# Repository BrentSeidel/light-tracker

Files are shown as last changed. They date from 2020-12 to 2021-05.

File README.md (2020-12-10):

# light-tracker
This is primarily a development project to get a working pan-tilt
head driven by stepper motors that can be used for a variety of
applications (the one in the back of my mind is pointing a radio
telescope).  This project uses a square 2x2 array of
photo-transistors separated by a X shaped shade and a
microcontroller to drive the steppers to equalize the light to the
phototransistors.

## Dependencies
### 3D Models
* The 3D models use items from my "things" repository at https://github.com/BrentSeidel/Things.git
* The gears come from sadr0b0t's "pd-gears" repository at https://github.com/sadr0b0t/pd-gears.git
### Software
* The software is written in a tiny-lisp from https://github.com/BrentSeidel/Ada-Lisp.git
* The hardware interfaces are from https://github.com/BrentSeidel/BBS-BBB-Ada.git
* I'm using an Arduino-Due as the microcontroller using https://github.com/BrentSeidel/Ada-Arduino-Due.git
* The low-level runtime should eventually wind up in AdaCore's "bb-runtimes" repostory at https://github.com/AdaCore/bb-runtimes.git
* I have a runtime version in my for at https://github.com/BrentSeidel/bb-runtimes.git, but
due to changes upstream, it no longer builds and I haven't had the time
to figure out why.
* It should be possible to adapt this to another microcontroller, either
bare metal or Linux based (such as a Raspberry PI).

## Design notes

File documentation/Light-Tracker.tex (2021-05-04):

\documentclass[10pt, openany]{book}

\usepackage{fancyhdr}
\usepackage{imakeidx}

\usepackage{amsmath}
\usepackage{amsfonts}

\usepackage{geometry}
\geometry{letterpaper}

\usepackage{fancyvrb}
\usepackage{fancybox}

\usepackage{gensymb}
\usepackage{pstricks}
\usepackage{graphicx}
\DeclareGraphicsExtensions{.eps}
\DeclareGraphicsRule{.eps}{eps}{.eps}{}

\usepackage{url}
%
% Rules to allow import of graphics files in EPS format
%
\usepackage{graphicx}
\DeclareGraphicsExtensions{.eps}
\DeclareGraphicsRule{.eps}{eps}{.eps}{}
%
%  Include the listings package
%
\usepackage{listings}
%
%  Define Tiny Lisp based on Common Lisp
%
\lstdefinelanguage[Tiny]{Lisp}[]{Lisp}{morekeywords=[13]{atomp, bit-vector-p, car, cdr, char-downcase, char-code, char-upcase, compiled-function-p, dowhile, dump, exit, fresh-line, if, code-char, lambda, msg, nullp, parse-integer, peek8, peek16, peek32, poke8, poke16, poke32, quote, read-line, reset, setq, simple-bit-vector-p, simple-string-p, simple-vector-p, string-downcase, string-upcase}}
%
% Macro definitions
%
\newcommand{\operation}[1]{\textbf{\texttt{#1}}}
\newcommand{\package}[1]{\texttt{#1}}
\newcommand{\function}[1]{\texttt{#1}}
\newcommand{\constant}[1]{\emph{\texttt{#1}}}
\newcommand{\keyword}[1]{\texttt{#1}}
\newcommand{\datatype}[1]{\texttt{#1}}
\newcommand{\tl}{Tiny-Lisp}
\newcommand{\cl}{Common Lisp}
%
% Front Matter
%
\title{Light Tracker}
\author{Brent Seidel \\ Phoenix, AZ}
\date{ \today }
%========================================================
%%% BEGIN DOCUMENT
\begin{document}
%
% Produce the front matter
%
\frontmatter
\maketitle
\begin{center}
This document is \copyright 2021 Brent Seidel.  All rights reserved.

\paragraph{}Note that this is a draft version and not the final version for publication.
\end{center}
\tableofcontents

\mainmatter
%----------------------------------------------------------
\chapter{Introduction}
The light tracker was conceived as a way to test a 3-D printed pan and tilt platform.

%----------------------------------------------------------
\chapter{Hardware}
\section{Electronics}
\subsection{Micro-controller Requirements}
There are four photo-transistors light sensors, thus 4 analog inputs are required.  Each stepper motor requires 4 digital output lines.  For the two steppers, a total of 8 outputs are required.  Should limit switches be added, a few digital inputs will also be required.  The micro-controller that I'm using is an Arduino Due, which has ample resources for this project.

\subsection{Light Sensors}
Each light sensor consists of a photo-transistor in series with a 1k$\Omega$ resistor.  The center tap is connected to one of the analog inputs.  The sensors are arranged in a $2 \times 2$ grid with a ``+'' shaped shade between them.  The sensors are tied to the analog inputs as shown in figure \ref{fig:Sensors}.

\begin{figure}[htb]
  \begin{center}
    
    \caption{Light Sensor Arrangement}
    \label{fig:Sensors}
  \end{center}
\end{figure}

\subsection{Stepper Motor Control}
The stepper motors are controller by two TB6612 dual H-bridge controllers (Adafruit p/n 2448).  Each of these controls one of the stepper motors.  The first one, H1 is used to control the panning motor and the other one, H2 is used to control the tilt motor.

\subsection{Connections}
Both the controller and the pan tilt have two DB9 connectors (see figure \ref{fig:D9}).  One is used for the sensors (see table \ref{tbl:Sensor}) and the other is used for the stepper motors (see table \ref{tbl:Stepper}).

The cables are made using CAT5 cables and are wired up so that pins 1 \& 6, 2 \& 7, 4 \& 9, and 5 \& 9 are each on a separate twisted pair.  Which pair used is not particularly important, just that the pair is wired the same at both ends.

\begin{figure}[htb]
  \begin{center}
    
    \caption{DB-9 Connector Pin Numbers}
    \label{fig:D9}
  \end{center}
\end{figure}

\begin{table}
  \begin{center}
    \caption{Light Sensor Pinout}
    \label{tbl:Sensor}
    \begin{tabular}[htb]{|c|l|}
      \hline
      Pin & Usage \\
      \hline
      1 & Analog 4 \\
      2 & Analog 3 \\
      3 & n.c. \\
      4 & Analog 2 \\
      5 & Analog 1 \\
      6 & +V (for analog 4)\\
      7 & +V (for analog 3)\\
      8 & +V (for analog 2)\\
      9 & +V (for analog 1)\\
      \hline
    \end{tabular}
  \end{center}
\end{table}

\begin{table}
  \begin{center}
    \caption{Stepper Motor Connector Pinout}
    \label{tbl:Stepper}
    \begin{tabular}[htb]{|c|l|}
      \hline
      Pin & Usage \\
      \hline
      1 & H1, MA+ (gpio 22 green) \\
      2 & H1, MB+ (gpio 24 red) \\
      3 & n.c. \\
      4 & H2, MA+ (gpio 28 green) \\
      5 & H2, MB+ (gpio 30 red) \\
      6 & H1, MA- (gpio 23 grey) \\
      7 & H1, MB- (gpio 25 yellow) \\
      8 & H2, MA- (gpio 29 grey) \\
      9 & H2, MB- (gpio 31 yellow) \\
      \hline
    \end{tabular}
  \end{center}
\end{table}

\section{Mechanical}
\subsection{Gearing}
Both stepper motors have a 20 tooth gear and are 400 steps per revolution.

The tilt gear has 50 teeth giving a $\frac{2}{5}$ gear ratio.  With the gearing, 1000 steps of the motor will completely rotate the tilt frame.  This is 0.36\degree per step or 2.78 steps per degree.

The pan gear has 100 teeth giving a $\frac{1}{5}$ gear ratio.  With the gearing, 2000 steps of the motor will completely rotate the pan head, giving 0.18\degree per steps or 5.56 steps per degree.

\subsection{Control Box}

\subsection{Pan/Tilt Head}

%----------------------------------------------------------
\chapter{Software}

\end{document}

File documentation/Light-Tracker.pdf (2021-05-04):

# Light Tracker

Brent Seidel
Phoenix, AZ

March 10, 2021

ii

This document is

c 2021 Brent Seidel. All rights reserved.

Note that this is a draft version and not the final version for publication.

# Contents

1 Introduction | 1
2 Hardware | 2
3 Software | 5

iii

iv | CONTENTS

# Chapter 1

# Introduction

The light tracker was conceived as a way to test a 3-D printed pan and tilt platform.

1

# Chapter 2

# Hardware

## 2.1 Electronics

### 2.1.1 Micro-controller Requirements

There are four photo-transistors light sensors, thus 4 analog inputs are required. Each stepper motor requires 4 digital output lines. For the two steppers, a total of 8 outputs are required. Should limit switches be added, a few digital inputs will also be required. The micro-controller that I’m using is an Arduino Due, which has ample resources for this project.

### 2.1.2 Light Sensors

Each light sensor consists of a photo-transistor in series with a 1kΩ resistor. The center tap is connected to one of the analog inputs. The sensors are arranged in a 2 × 2 grid with a “+” shaped

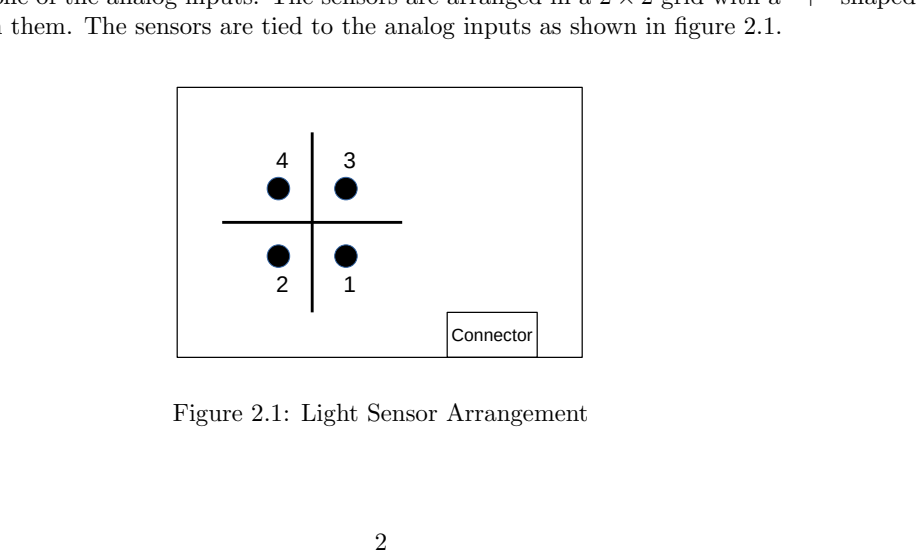
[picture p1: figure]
Connector; Figure 2.1: Light Sensor Arrangement

shade between them. The sensors are tied to the analog inputs as shown in figure 2.1.

2.2. MECHANICAL | 3

Table 2.1: Light Sensor Pinout
Pin | Usage
1 2 3 4 5 6 7 8 9 | Analog 4 Analog 3 n.c. Analog 2 Analog 1 +V (for analog 4) +V (for analog 3) +V (for analog 2) +V (for analog 1)

### 2.1.3 Stepper Motor Control

The stepper motors are controller by two TB6612 dual H-bridge controllers (Adafruit p/n 2448). Each of these controls one of the stepper motors. The first one, H1 is used to control the panning motor and the other one, H2 is used to control the tilt motor.

### 2.1.4 Connections

Both the controller and the pan tilt have two DB9 connectors (see figure 2.2). One is used for the

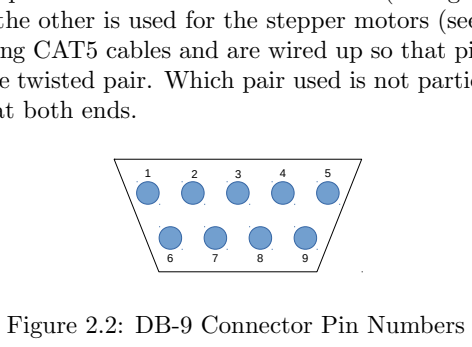
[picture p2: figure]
Figure 2.2: DB-9 Connector Pin Numbers

sensors (see table 2.1) and the other is used for the stepper motors (see table 2.2).
The cables are made using CAT5 cables and are wired up so that pins 1 & 6, 2 & 7, 4 & 9, and 5 & 9 are each on a separate twisted pair. Which pair used is not particularly important, just that the pair is wired the same at both ends.

## 2.2 Mechanical

### 2.2.1 Gearing

Both stepper motors have a 20 tooth gear and are 400 steps per revolution. The tilt gear has 50 teeth giving a 2
5

gear ratio. With the gearing, 1000 steps of the motor will completely rotate the tilt frame. This is 0.36◦per step or 2.78 steps per degree. The pan gear has 100 teeth giving a 1
5

gear ratio. With the gearing, 2000 steps of the motor will completely rotate the pan head, giving 0.18◦per steps or 5.56 steps per degree.

4 | CHAPTER 2. HARDWARE

Table 2.2: Stepper Motor Connector Pinout
Pin | Usage
1 2 3 4 5 6 7 8 9 | H1, MA+ (gpio 22 green) H1, MB+ (gpio 24 red) n.c. H2, MA+ (gpio 28 green) H2, MB+ (gpio 30 red) H1, MA- (gpio 23 grey) H1, MB- (gpio 25 yellow) H2, MA- (gpio 29 grey) H2, MB- (gpio 31 yellow)

### 2.2.2 Control Box

### 2.2.3 Pan/Tilt Head

# Chapter 3

# Software

5

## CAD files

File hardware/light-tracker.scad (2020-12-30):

use <../../Things/bbs_constants.scad>
use <../../Things/bbs_connectors.scad>

module LOCAL_led(height)
{
  lead_space = 2.54;
  translate([0, lead_space/2, -0.5]) cube([1, 1, height]);
  translate([0, -lead_space/2, -0.5]) cube([1, 1, height]);
  translate([-20, lead_space/2, -0.5]) cube([41, 1, height/2]);
  translate([-20, -lead_space/2, -0.5]) cube([41, 1, height/2]);
}
module phototransitor_mount()
{
  difference()
  {
    union()
    {
      cube([40, 80, 4]);
      translate([0, 39, 0]) cube([40, 2, 40]);
      translate([19, 20, 0]) cube([2, 40, 40]);
      translate([-20, 0, 0]) cube([20, 30, 4]);
    }
    union()
    {
      translate([10, 10, -0.5]) cylinder(r=screw_8_size()/2, h=5);
      translate([30, 10, -0.5]) cylinder(r=screw_8_size()/2, h=5);
      translate([10, 70, -0.5]) cylinder(r=screw_8_size()/2, h=5);
      translate([30, 70, -0.5]) cylinder(r=screw_8_size()/2, h=5);
      translate([14, 34, 0]) LOCAL_led(5);
      translate([14, 46, 0]) LOCAL_led(5);
      translate([26, 34, 0]) LOCAL_led(5);
      translate([26, 46, 0]) LOCAL_led(5);
      translate([-10, 15, -0.5]) rotate([0, 0, 90]) bbs_d_cutout(1, 5);
    }
  }
}

rotate([0, 0, 0]) phototransitor_mount();

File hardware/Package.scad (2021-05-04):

use <../../Things/bbs_arduino.scad>
use <../../Things/bbs_boards.scad>
use <../../Things/bbs_breadboard.scad>
use <../../Things/bbs_connectors.scad>
use <../../Things/bbs_constants.scad>
use <../../Things/bbs_panel.scad>
use <../../Things/bbs_rack.scad>
use <../../Things/bbs_switches.scad>
use <../../Things/bbs_tray.scad>
//
//  This file contains items for mounting and housing the electronics to control the light-tracker.
//
module tray()
{
  screw_size = 3*screw_6_size()/4;
  screw_hole = screw_6_size()/2;
  difference()
  {
    union()
    {
      bbs_tray(5, 7, false);
      translate([150, 70, 0]) rotate([0, 0, 90]) bbs_tb6612_standoffs(5, screw_size, 12);
      translate([115, 70, 0]) rotate([0, 0, 90]) bbs_tb6612_standoffs(5, screw_size, 12);
      translate([0, 10, 0]) bbs_arduino_mega2560_standoffs(5, screw_size, 12);
      translate([110, 10, 0]) bbs_quarter_permaprotoboard_standoffs(5, screw_size, 12);
    }
    union()
    {
      translate([150, 70, -1]) rotate([0, 0, 90]) bbs_tb6612_standoffs(7, screw_hole, 12);
      translate([115, 70, -1]) rotate([0, 0, 90]) bbs_tb6612_standoffs(7, screw_hole, 12);
      translate([0, 10, -1]) bbs_arduino_mega2560_standoffs(7, screw_hole, 12);
      translate([110, 10, -1]) bbs_quarter_permaprotoboard_standoffs(7, screw_hole, 12);
      translate([25, 15, -1]) minkowski()
      {
        cube([30, 80, 7]);
        cylinder(r=5, h=7);
      }
      translate([125, 15, -1]) minkowski()
      {
        cube([10, 80, 7]);
        cylinder(r=5, h=7);
      }
      translate([75, 15, -1]) minkowski()
      {
        cube([5, 80, 7]);
        cylinder(r=5, h=7);
      }
    }
  }
}

module rack()
{
  bbs_rack(5, 7, 3);
}

module connector_panel()
{
  difference()
  {
    bbs_panel(5, 3);
    union()
    {
      translate([30, 40, -0.5]) rotate([0, 0, 90]) bbs_d_cutout(1, 3);
      translate([30, 80, -0.5]) rotate([0, 0, 90]) bbs_d_cutout(1, 3);
      translate([18, 40, 1.5]) linear_extrude(height = 0.6) rotate([0, 0, -90])
              text("Stepper", halign="center", valign="center", size=6, font="Liberation Sans:Bold");
      translate([18, 80, 1.5]) linear_extrude(height = 0.6) rotate([0, 0, -90])
              text("Sensors", halign="center", valign="center", size=6, font="Liberation Sans:Bold");
    }
  }
}

module switch_panel()
{
  difference()
  {
    bbs_panel(5, 2);
    union()
    {
      translate([20, 90, -0.1]) bbs_spdt_switch_cutout(2.2);
      translate([20, 70, -0.1]) bbs_spdt_switch_cutout(2.2);
      translate([20, 50, -0.1]) bbs_spdt_switch_cutout(2.2);
      translate([20, 30, -0.1]) bbs_spdt_switch_cutout(2.2);
      translate([7, 90, 1.5]) linear_extrude(height = 0.6) rotate([0, 0, -90])
              text("Stop", halign="center", valign="center", size=6, font="Liberation Sans:Bold");
      translate([30, 90, 1.5]) linear_extrude(height = 0.6) rotate([0, 0, -90])
              text("Run", halign="center", valign="center", size=6, font="Liberation Sans:Bold");
    }
  }
}

//tray();
//translate([150, 70, 10]) rotate([0, 0, 90]) color("red") bbs_tb6612();
//translate([115, 70, 10]) rotate([0, 0, 90]) color("red") bbs_tb6612();
//translate([0, 10, 10]) color("green") bbs_arduino_mega2560();
//translate([110, 10, 10]) color("red") bbs_quarter_permaprotoboard();
//rack();
//connector_panel();
switch_panel();

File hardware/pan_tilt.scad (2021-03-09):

//
//  Models for pan and tilt mounting
//
use <../../Things/bbs_constants.scad>
use <../../Things/bbs_shapes.scad>
use <../../Things/bbs_stepper.scad>
use <../../pd-gears/pd-gears.scad>

module LOCAL_base_arm()
{
  d1 = pitch_radius(5, 100);
  d2 = pitch_radius(5, 20);
  width=20;
  length=d1+d2+0;
  difference()
  {
    union()
    {
      translate([-width/2, 0, 0]) cube([width, length, 4]);
      translate([0, length, 0]) cylinder(r=10, h=4);
      translate([-width/2, d1+5, 0]) cube([width, 4, 20]);
    }
    union()
    {
      translate([0, length, -0.5]) cylinder(r=screw_8_size()/2, h=5);
      translate([0, length-20, -0.5]) cylinder(r=screw_8_size()/2, h=5);
      translate([0, length, 2]) cylinder(r=screw_8_size()/2+2.5, h=5);
      translate([0, length-20, 2]) cylinder(r=screw_8_size()/2+2.5, h=5);
      translate([0, d1+4.5, 15]) rotate([-90, 0, 0]) cylinder(r=2, h=5);
      translate([6, d1+4.5, 15]) rotate([-90, 0, 0]) cylinder(r=2, h=5);
      translate([-6, d1+4.5, 15]) rotate([-90, 0, 0]) cylinder(r=2, h=5);
    }
  }
}
module LOCAL_base_motor()
{
  d1 = pitch_radius(5, 100);
  d2 = pitch_radius(5, 20);
  difference()
  {
    rotate([0, 0, 0]) translate([-20, -15, 0]) cube([40, 135, 4]);
    union()
    {
      translate([0, (d1+d2), -0.5]) bbs_NEMA17_holes(5, true);
      translate([-0.5, 116, -0.5]) cube([1, 5, 1.5]);
    }
  }
}
//
//  This is the base that everything rests on.  it contains a hole for the vertical
//  shaft and a mount for a stepper motor.
//
module base(pan_shaft)
{
  difference()
  {
    union()
    {
      LOCAL_base_arm();
      rotate([0, 0, 90]) LOCAL_base_arm();
      rotate([0, 0, 180]) LOCAL_base_arm();
      rotate([0, 0, 270]) LOCAL_base_arm();
      rotate([0, 0, 45]) LOCAL_base_motor();
    }
    translate([0, 0, -0.5]) cylinder(r=pan_shaft, h=5);
  }
}
//
//  Feet to support the base.  These are bolted to the base and have holes where legs could
//  be attached to them.  They can also be used without legs to support the base on a table
//  top, or similar.
//
module foot()
{
  union()
  {
    difference()
    {
      cube([20, 40, 4]);
      union()
      {
        translate([10, 10, -0.5]) cylinder(r=screw_8_size()/2, h=5, $fn=12);
        translate([10, 30, -0.5]) cylinder(r=screw_8_size()/2, h=5, $fn=12);
      }
    }
    rotate([10, 0, 0]) difference()
    {
      cube([20, 4, 40]);
      union()
      {
        translate([10, -0.5, 10]) rotate([-90, 0, 0]) cylinder(r=screw_8_size()/2, h=5, $fn=12);
        translate([10, -0.5, 30]) rotate([-90, 0, 0]) cylinder(r=screw_8_size()/2, h=5, $fn=12);
      }
    }
    difference()
    {
      cube([4, 30, 20]);
      translate([-0.5, 0, 20]) rotate([-30, 0, 0]) cube([5, 40, 20]);
    }
  }
}
//
//  This part sits on the base.  It has an integrated gear that interfaces with with a gear
//  on the stepper motor.
//
module LOCAL_pan_panel(tilt_shaft)
{
  d1 = pitch_radius(5, 50);
  d2 = pitch_radius(5, 20);
  difference()
  {
    union()
    {
      cube([50, 4, 25]);
      hull()
      {
        translate([25, 4, 25]) rotate([90, 0, 0]) cylinder(r=25, h=4);
        translate([25, 4, 100]) rotate([90, 0, 0]) cylinder(r=15, h=4);
      }
      translate([50, 4, 0]) rotate([0, -90, 0]) bbs_fillet(10, 50);
      translate([0, 0, 0]) rotate([0, -90, 180]) bbs_fillet(10, 50);
    }
    union()
    {
      translate([25, 4.5, 100]) rotate([90, 0, 0]) cylinder(r=tilt_shaft, h=5);
      translate([25, 4.5, 20]) rotate([90, 0, 0]) cylinder(r=7, h=5);
      translate([25, 4.5, 80]) rotate([90, 0, 0]) cylinder(r=10, h=5);
      translate([4, 4.5, 12]) rotate([90, 0, 0]) cylinder(r=2, h=5);
      translate([4, 4.5, 18]) rotate([90, 0, 0]) cylinder(r=2, h=5);
      translate([46, 4.5, 12]) rotate([90, 0, 0]) cylinder(r=2, h=5);
      translate([46, 4.5, 18]) rotate([90, 0, 0]) cylinder(r=2, h=5);
      translate([25, 4.5, 100-d1-d2]) rotate([90, 0, 0]) bbs_NEMA17_holes(5, true);
    }
  }
}

module pan(pan_shaft, tilt_shaft)
{
  difference()
  {
    gear(5, 100, 4, 1);
    union()
    {
      translate([0, 0, -0.5]) cylinder(r=pan_shaft, h=5);
      for(t=[0:60:360])
      {
        rotate([0, 0, t]) translate([30, 0, -0.5]) cylinder(r=10, h=5);
      }
      for(t=[-45:30:45])
      {
        rotate([0, 0, t]) translate([60, 0, -0.5]) cylinder(r=10, h=5);
        rotate([0, 0, t]) translate([-60, 0, -0.5]) cylinder(r=10, h=5);
      }
    }
  }
  translate([-25, -59, 4]) LOCAL_pan_panel(tilt_shaft);
  translate([-25, 55, 4]) LOCAL_pan_panel(tilt_shaft);
}
//
//  This part attaches to the pan part and is used to tilt up and down.
//
module tilt(tilt_shaft)
{
  difference()
  {
    union()
    {
      gear(5, 50, 4, 1);
      translate([20, -16, 4]) rotate([0, -90, 0]) bbs_fillet(10, 40);
      translate([-20, -20, 4]) rotate([0, -90, 180]) bbs_fillet(10, 40);
    }
    union()
    {
      translate([0, 0, -0.5]) cylinder(r=tilt_shaft, h=5);
      for(t=[0:60:180])
      {
        rotate([0, 0, t]) translate([23, 0, -0.5]) cylinder(r=8, h=5);
      }
    }
  }
  difference()
  {
    translate([-20, -20, 4]) cube([20, 4, 100]);
    union()
    {
      for(z=[25:20:100])
      {
        translate([-10, -20.5, z]) rotate([-90, 0, 0]) cylinder(r=screw_8_size()/2, h=5);
      }
    }
  }
}
//
//  Drive gears for the stepper motors
//
module drive_gear()
{
  difference()
  {
    gear(5, 20, 4, 1);
    translate([0, 0, -0.5]) bbs_NEMA17_dshaft(5);
  }
}

//rotate([0, -90, 0]) foot();
//base(screw_8_size()/2);
translate([0, 0, 5]) pan(screw_8_size()/2, screw_8_size()/2);
//translate([0, -54, 104]) rotate([-90, 0, 0]) color("green") tilt(screw_8_size()/2);
//translate([0, 54, 104]) rotate([-90, 0, 180]) color("red") tilt(screw_8_size()/2);
//translate([0, -50, 104-pitch_radius(5, 50)-pitch_radius(5, 20)]) rotate([90, 7, 0])tilt_gear();
//translate([0, -54, 110]) cube([10, 108, 10]);

//tilt(screw_8_size()/2);
//translate([60, 0, 0]) drive_gear();

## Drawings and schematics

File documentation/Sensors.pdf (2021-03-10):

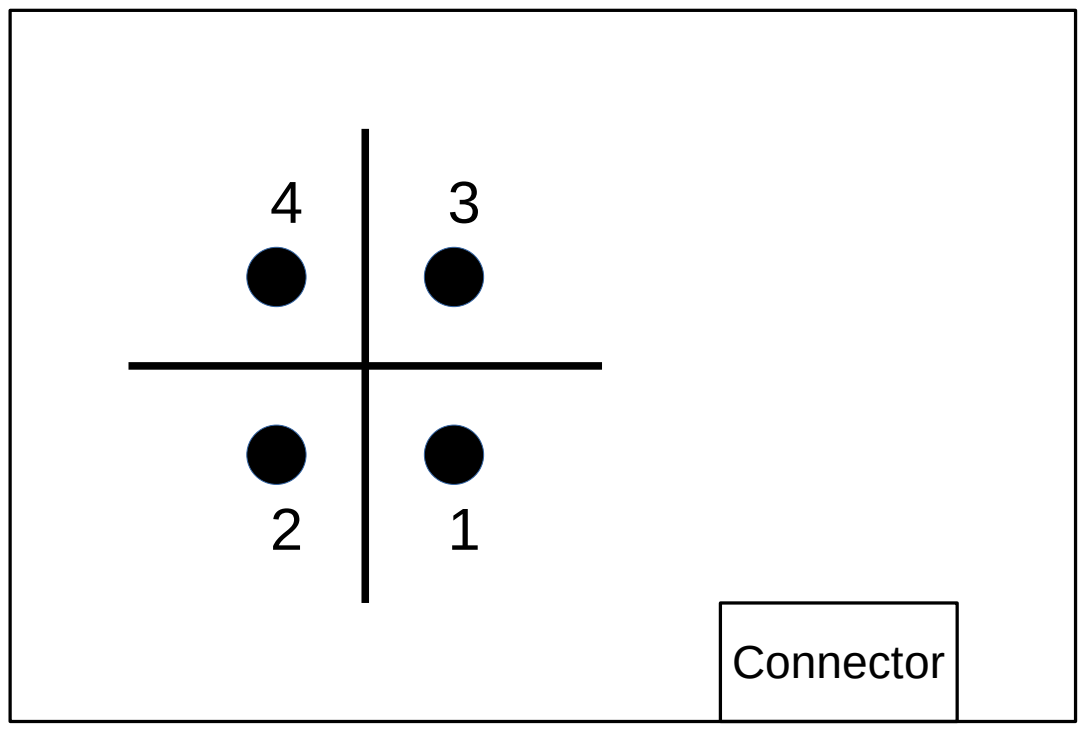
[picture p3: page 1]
Connector

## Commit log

2020-12-10 Add model for pan-tilt head.
    [pan_tilt.scad]
2020-12-11 Add model for light shade.
    [light-tracker.scad]
2020-12-24 Add base and feet for pan-tilt head.
    [pan_tilt.scad]
2020-12-30 Add holes for cable ties to pan head. Add hole for connector to light tracker.
    [light-tracker.scad, pan_tilt.scad]
2021-03-02 Add initial software. It sorta works, but there is a singularity when the sensor is pointing vertically.
    [Package.scad]
2021-03-04 Add a dead band to both tilt and pan to help reduce jitter due to noise in the analog lines.
2021-03-09 Move information about gear ratios to documentation from an OpenSCAD file so that it will be more accessible.
    [pan_tilt.scad]
2021-03-10 Move sensor and connector information from comments in source code to documentation. To support this some figures were created.
2021-03-10 Move stepper motor information from source code comments to documentation.
2021-05-04 Update code to work with changes to Ada-Lisp-Embedded. Add a panel with a Run/Stop switch that gets connected to GPIO 52. Make loop in (track) function now depend on state of switch rather than numbe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
    [Package.scad]
